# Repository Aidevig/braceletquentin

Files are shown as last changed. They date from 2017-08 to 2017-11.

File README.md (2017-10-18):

# braceletquentin
Schémas, code et documentation du bracelet développé par Quentin

#	Code
Code pour Adafruit feather bluefruit m0

# Schemas
Fichier eagles, BOM et archives avec gerber pour fabrication de la carte

# Utilitaire USB
Tentative de programme récupérant les données stockées sur le bracelet directement en USB.
Echec : trop lent.

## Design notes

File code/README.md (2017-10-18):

# LIRE CE README EN ENTIER!

# Code pour ADAFRUIT FEATHER M0 BLUEFRUIT LE

Ce code est réalisé pour une carte adafruit feather bluefruit m0 a venir souder dans le PCB assemblé de la section schema.
Ce microcontroleur utilisant un SAMD21 et non un ATMEGA, il n'est pas compatible pour les arduinos autre que ceux embarquant un SAMD21 (arduino zero, micro?, feather m0..)

# Fonctionnalités Développées

- Gestion mémoire flash : module carte SD (connection SPI)
- Connectivité bluetooth et envois alerte basique (connection SPI intégré sur le feather m0 bluefruit)
- Enregistrement de fichiers audios (WAV 8KHz) sur carte SD grâce au module microphone max4466 adafruit
- lecture de l'accélération en 3D par accéléromètre ADXL345 (connection I2C)
- lecture du rythme cardiaque par capteur cardiaque BH1790GLC (connection I2C)
- Détection alerte si le rythme cardiaque n'est pas compris entre les seuils min et max
- Pseudo Real Time Clock qui permet de dater les logs
- Lecture des seuils min et max pour le rythme cardiaque depuis un fichier texte sur la carte SD (conf.txt)
- gestion de différents types d'appuis sur un bouton poussoir (long, 1 court, 2 courts, 3 courts) BTN1 voir aidevig_pinDefinition
- Possibilité d'activer la débug console de l'IDE arduino en passant le #DEFINE DEBUG à 1

# Fonctionnement du Bracelet

- S'allume lorsqu'on branche la batterie adafruit adaptée et se recharge lorsqu'on branche le bracelet en USB.
- A l'allumage, la LED ROUGE doit clignoter quelques secondes très rapidement. Sinon, problème: réessayer plusieurs fois.
- A l'allumage, va lire les seuils limite dans le fichier conf.txt sur la carte SD
- A l'allumage, le bracelet configure sa connection bluetooth : il s'appel "GO-SAFE"
- Enregistre toutes les secondes les valeurs de l'accéléromètre x,y,z et le rythme cardiaque en datant le log dans le fichier DATALOG.txt
- Lorsqu'on appuie longtemps sur le bouton, lance un enregistrement audio qui s'arrête lorsque celui ci est relaché. La LED rouge s'allume pendant l'enregistrement
- Lorsqu'on appuie une fois sur le bouton, envois une alerte au mobile via bluetooth
- Si le rythme cardiaque est hors des seuils minCardio et maxCardio, le bracelet va proposer une alerte (LED Rouge clignotante) pendant 7 secondes.
		*Si durant ces 7 secondes, on appuie 2 fois sur le bouton, on arrête l'alerte
		*Sinon, l'alerte est envoyée.

# TO DO

- Développer l'utilisation du bluetooth en parallèle avec un développeur de l'appli mobile
- améliorer l'utilisation des LED
- Calibrer les valeurs de l'accéléromètre et du rythme cardiaque
- Calibrer les interruptions de l'accéléromètre (voir datasheet + debug console qui affiche les IT accéléromètre triggered)
ATTENTION : les IT accéléromètre sont désactivées en mode non debug
- Informer du niveau de batterie restant lors de 3 appuis (voir tuto adafruit m0 bluefruit, liens plus bas)
- Gérer le vibreur plutôt qu'une LED lors de la proposition d'alerte
- Créer des alertes automatiques sur IT accéléromètre où valeurs particulières d'accélération

# TUTO POUR PROGRAMMER LE FEATHER M0 BLUEFRUIT LE

- PREMIEREMENT : suivre ce tuto https://learn.adafruit.com/adafruit-feather-m0-bluefruit-le/setup
- télécharger l'archive Code de ce repository et extraire dans un répertoire du nom de votre choix
- Copier LE CONTENU du dossier librairies dans le dossier librairies de votre IDE Arduino ( .../mesdocuments/arduino/librairies)
- Ouvrir le fichier protoMesureQuentin.ino du répertoire protoMesureQuentin, brancher en USB le feather M0 Bluefruit LE, sélectionner le bon port dans l'IDE et cliquer sur téléverser

# En cas de problème

Contacter Quentin Van Straaten : vanstraatenquentin@gmail.com

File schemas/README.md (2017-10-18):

# Schema Electronique

Le fichier schema electronique est un fichier Eagle. Il contient le schéma électronique complet du prototype. Pour le réaliser, j'ai utilisé les schémas mis à disposition par adafruit sur ses différents modules. Ils sont aisément trouvables.

# Composants :
Microcontrolleur: 
Adafruit Feather M0 Bluefruit LE	https://www.adafruit.com/product/2995

Accéléromètre:
ADXL345 							https://www.adafruit.com/product/1231

Capteur Cardiaque:
BH1790GLC							http://www.rohm.com/web/global/products/-/product/BH1790GLC

micro:
Electret Microphone Amplifier - MAX4466 with Adjustable gain	https://www.adafruit.com/product/1063

# PCB
Le répertoire PCB contient le .brd (format eagle). Il contient également les gerbers et la BOM.

# Commander un PCB
Afin de commander un pcb assemblé il suffit d'utiliser les fichiers contenus dans l'archive PCB-BODYGUARD.rar et la BOM car les composants sont déjà correspondants entre la BOM et le .brd

Passer par le site EMSPROTO et compter deux semaines pour des prix corrects.
	
# A faire
-La carte électronique est conçue sans bouton bien que les trous soient présent pour venir en souder deux. Il faut également ajouter un vibreur sur le pin A0.
Ceci permet d'ajouter ces périphériques directement sur la structure mécanique de l'objet.
-La carte électronique vient également sans son microcontrôleur feather M0 Bluefruit qui doit être soudé dessus. Il est immaginable d'ajouter un connecteur à la place afin d'éviter d'avoir à souder le microcontrôleur.
-La batterie utilisée est une batterie adafruit compatible avec le Feather M0 Bluefruit LE, elle se recharge lorsque le bracelet est branché en USB. Le bracelet doit être allumé pour se recharger.
-Un fil de la batterie doit être coupé et soudé a un switch intégré à la structure mécanique afin de pouvoir allumer et éteindre le bracelet 	
	
# ATTENTION
Afin d'optimiser l'espace sur la carte, j'ai supprimé les boutons poussoirs. Il ne reste que le trou pour les connecter aux pins du microcontrôleur. Il faudra également connecter l'autre entrée à la masse.
Par conséquent, les fichiers eagles du schéma et de la board ne sont plus linkés. AUCUNE MODIFICATION SUR L'UN N'AURA D'EFFET SUR L'AUTRE

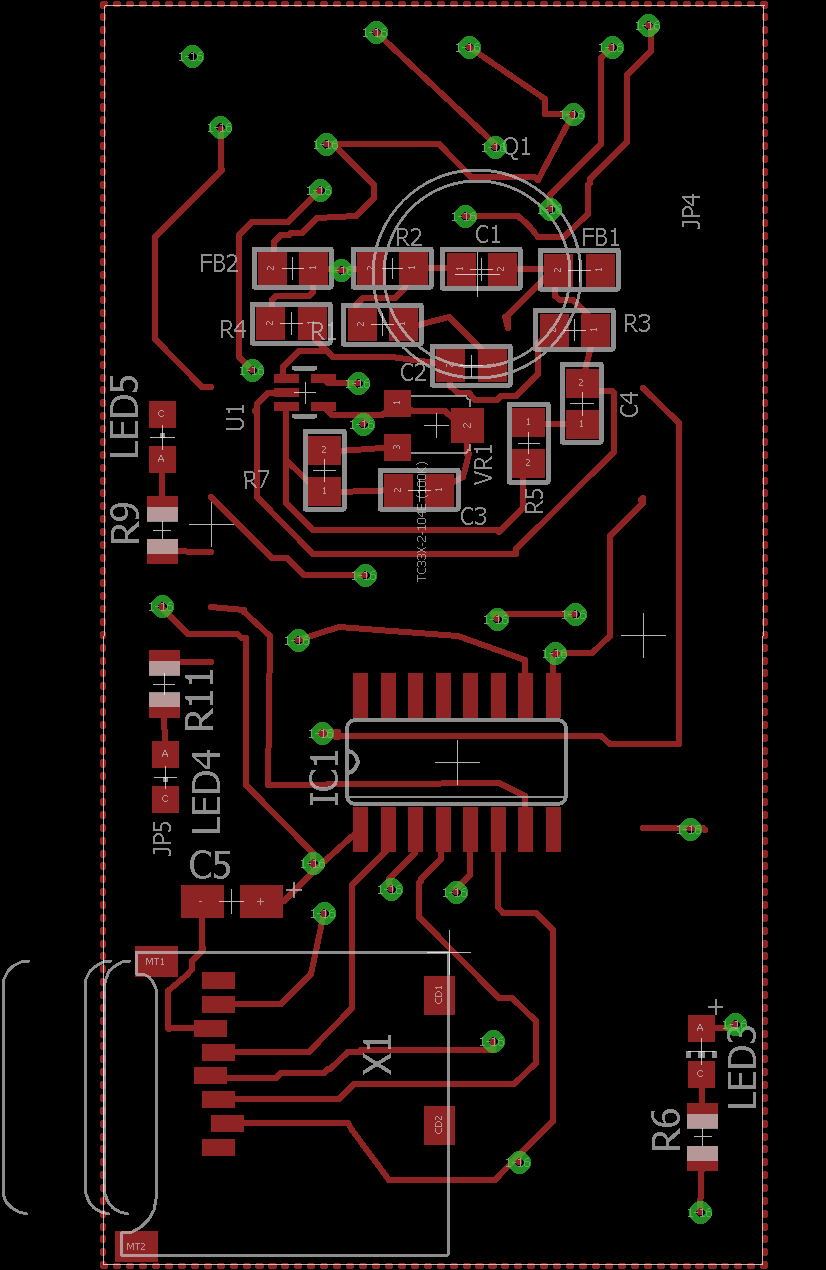
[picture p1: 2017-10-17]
schemas/PCB/gerbers/TOP.png

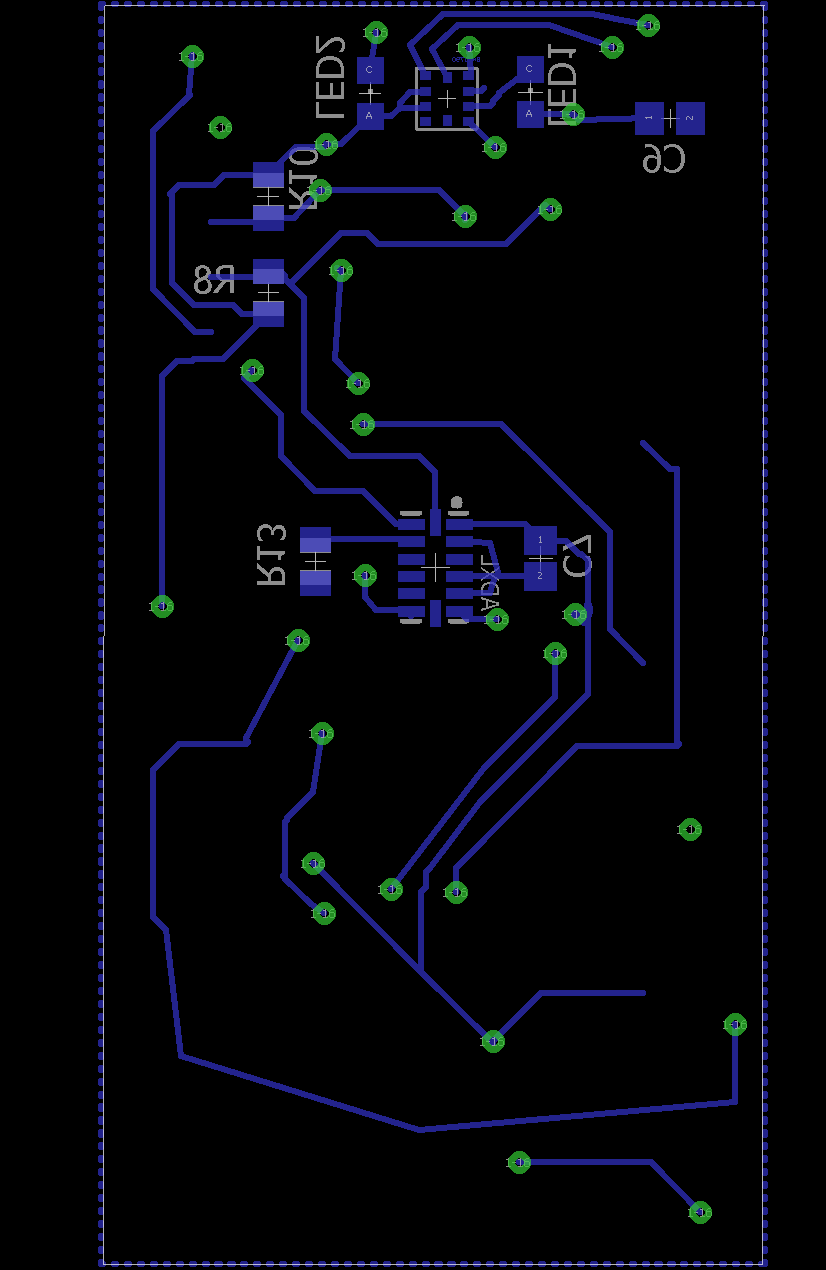
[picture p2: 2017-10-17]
schemas/PCB/gerbers/BOT.png

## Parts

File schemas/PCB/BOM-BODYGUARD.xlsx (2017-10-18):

Désignation | Quantity | Manufacturer | Reference Manufacturer | Supplier | Reference Supplier | MOUNTING TECHNOLOGY | Designator
Optical Sensor For Heart Rate Monitor | 1 | ROHM SEMICONDUCTOR | BH1790GLC-E2 | DIGIKEY | BH1790GLC-E2CT-ND | SMD | BH1790
LED BLUE-GREEN CLEAR 0603 SMD | 2 | ROHM SEMICONDUCTOR | SMLE13EC8TT86 | DIGIKEY | 846-1178-1-ND | SMD | LED1, LED2
LED green 0805 CMS | 1 | DIALIGHT | 5988270107F | FARNELL | 1850749 | SMD | LED5
LED RED 0805 CMS | 2 | DIALIGHT | 5988210107F | FARNELL | 1850747 | SMD | LED3, LED4
ADXL345BCCZ ACCELEROMETRE 3 AXES | 1 | ANALOG DEVICES | ADXL345BCCZ | FARNELL | 1853935 | SMD | ADXL
Buffer, Non-Inverseur | 1 | TEXAS INSTRUMENTS | CD74HC4050M | FARNELL | 1643824 | SMD | IC1
Connecteur carte SD | 1 | Adafruit | 1660 | MOUSER | 485-1660 | SMD | X1
Condensateur céramique multicouche CMS 100pF | 1 | MULTICOMP | MC0805N101J500CT | FARNELL | 1759203 | SMD | C3
Condensateur céramique multicouche CMS 0,01uF | 1 | MULTICOMP | MC0805F103Z500CT | FARNELL | 2665973 | SMD | C2
Condensateur céramique multicouche CMS 0,1uF | 2 | AVX | 08055C104KAT2A | FARNELL | 499687 | SMD | C1, C7
Condensateur céramique multicouche CMS 1uF | 1 | WALSIN | 0805B105K160CT | FARNELL | 2496946 | SMD | C6
Condensateur céramique multicouche CMS 10uF | 2 | WALSIN | 0805F106Z100CT | FARNELL | 2496998 | SMD | C4, C5
Resistance CMS 1K | 6 | MULTICOMP | MCHP05W4F1001T5E | FARNELL | 1576459 | SMD | R1, R2, R5, R6, R9, R11
Resistance CMS 10K | 3 | MULTICOMP | MCHP05W4F1002T5E | FARNELL | 1576473 | SMD | R8, R10, R13
Resistance CMS 22K | 1 | Welwyn | WCR0805-22KFI | FARNELL | 1099809 | SMD | R7
Resistance CMS 1M | 2 | MULTICOMP | MCHP05W4F1004T5E | FARNELL | 1576507 | SMD | R3, R4
Ferrite Beads 100MHz 600Ohm | 2 | WURTH ELEKTRONIK | 742792040 | MOUSER | 710-742792040 | SMD | FB1, FB2
Microphone | 1 | CUI INC | CMA-4544PF-W | DIGIKEY | 490-CMA-4544PF-W | Trans | Q1
Potentimètre variable 100KOhms | 1 | BOURNS | TC33X-2-104E | FARNELL | 1689864 | SMD | VR1
Ampli audio | 1 | MAXIMUM INTEGRATED PRODUCTS | MAX4466EXK+T | FARNELL | 2514501 | SMD | U1

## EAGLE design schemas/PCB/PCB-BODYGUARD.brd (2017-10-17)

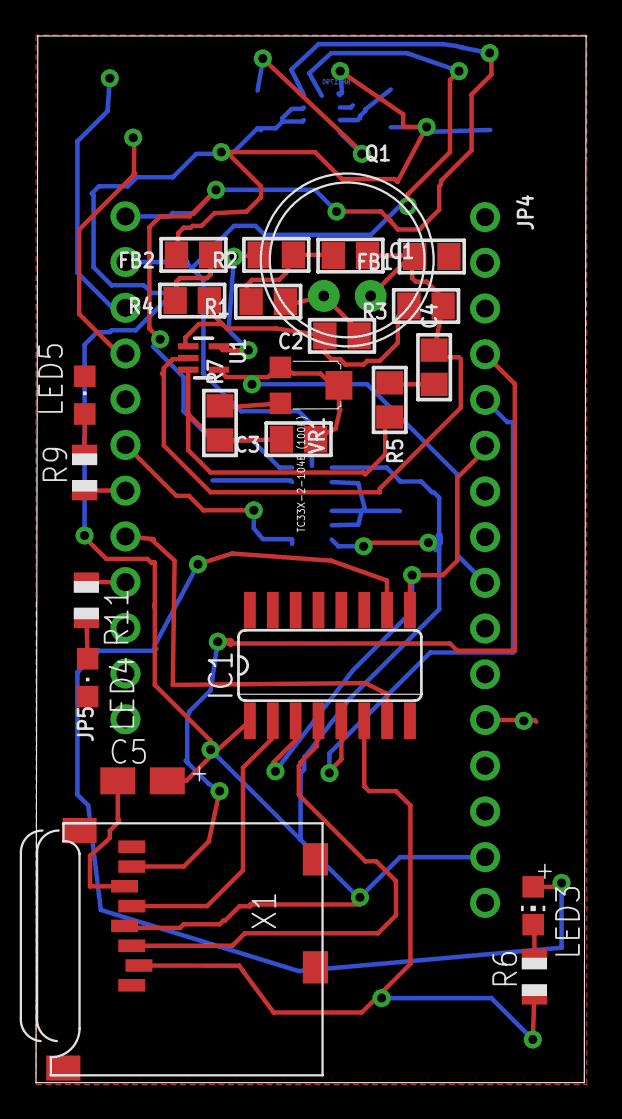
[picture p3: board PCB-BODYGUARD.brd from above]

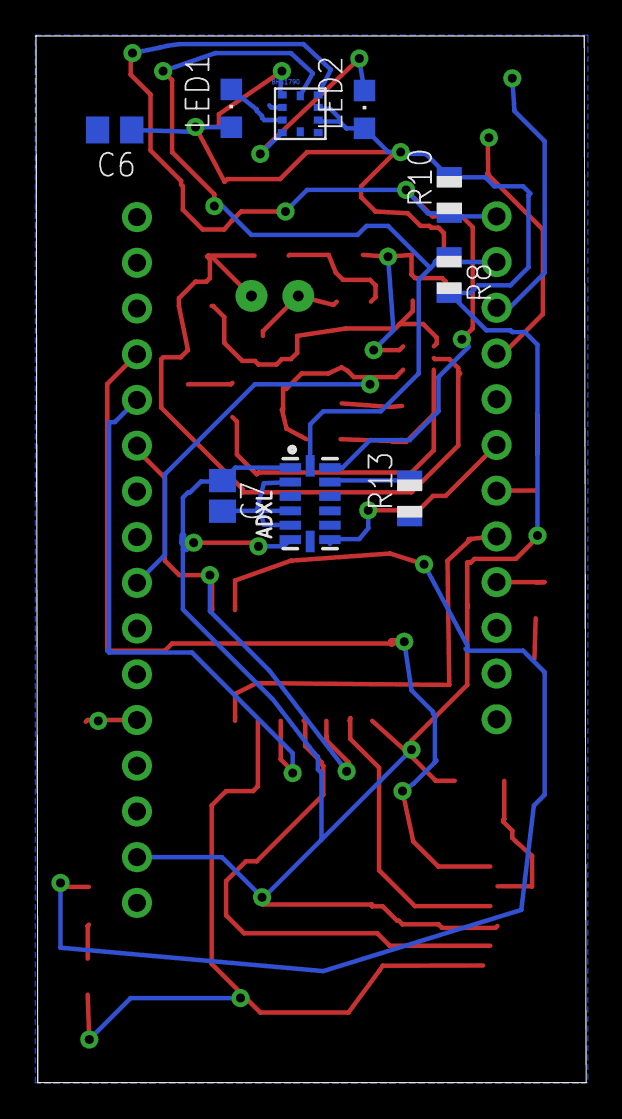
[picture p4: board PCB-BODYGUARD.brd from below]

Board: 2 copper layers, 30.6 x 58.1 mm, 35 parts (9 on the bottom side), 30 nets.

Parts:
ADXL: LGA14
BH1790: BH1790
C1: 0.1µF; 0805
C2: 0.01uF; 0805
C3: 100pF; 0805
C4: 10uF; 0805
C5: 10uF; A/3216-18R
C6: 1uF; C0805
C7: 0.1uF; C0805
FB1, FB2: FERRITE; 0805
IC1: 4050D; SO16
JP4: 1X16_ROUND
JP5: 1X12_ROUND
LED1, LED2, LED5: green; CHIPLED_0805
LED3: RED; CHIP-LED0805
LED4: Red; CHIPLED_0805
Q1: CMA-4544PF-W; ELECTRET_9.7
R1, R2, R5: 1K; 0805
R3, R4: 1M; 0805
R6, R9, R11: 1K; R0805
R7: 22K; 0805
R8, R10, R13: 10K; R0805
U1: MAX4466EXK+T; SC70-5
VR1: TC33X-2-104E (100K); TRIMPOT_BOURNS_TC33X-2
X1: MICROSD

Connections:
+3V3: ADXL.1, ADXL.6, BH1790.TEST2, BH1790.VCC, BH1790.VCC2, C5.+, C6.1, C7.1, FB2.2, IC1.1, JP4.15, LED1.A, LED2.A, R8.2, R10.2, X1.4
A3: C3.1, JP4.9, U1.4, VR1.1, VR1.2
AGND: C1.2, C4.2, FB1.2, Q1.-, R3.1, U1.2
AVCC: FB2.1, R2.2, R4.2, U1.5
D10: ADXL.8, JP5.7
D11: JP5.6, R9.1
D12: IC1.7, JP5.5
D13: JP5.4, R11.1
GND: ADXL.2, ADXL.4, ADXL.5, BH1790.GND, BH1790.TEST1, C5.-, C6.2, C7.2, FB1.1, IC1.8, IC1.11, IC1.14, JP4.13, LED4.C, LED5.C, R13.1, X1.6, X1.MT1, X1.MT2
MISO: JP4.4, X1.7
MOSI: IC1.5, JP4.5
unnamed: C3.2, R5.2, R7.1, U1.3
unnamed: R7.2, VR1.3
unnamed: C2.1, Q1.+, R1.1
unnamed: C1.1, R1.2, R2.1
unnamed: C2.2, R3.2, R4.1, U1.1
unnamed: BH1790.LED1, LED1.C
unnamed: C4.1, R5.1
unnamed: IC1.10, LED3.A
unnamed: IC1.2, X1.5
unnamed: IC1.6, R6.1, X1.2
unnamed: LED3.C, R6.2
unnamed: IC1.4, X1.3
unnamed: BH1790.LED2, LED2.C
unnamed: LED5.A, R9.2
unnamed: LED4.A, R11.2
SCK: IC1.3, IC1.9, JP4.6
SCL: ADXL.14, BH1790.SCL, JP5.11, R8.1
SDA: ADXL.13, BH1790.SDA, JP5.12, R10.1
SDO/ADDR: ADXL.12, R13.2

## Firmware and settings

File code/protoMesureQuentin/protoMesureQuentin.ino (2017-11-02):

/**************************************************************************/
/*!
    @section LICENSE

    Software License Agreement (BSD License)

    Copyright (c) 2017, Aidevig
    All rights reserved.

    Redistribution and use in source and binary forms, with or without
    modification, are permitted provided that the following conditions are met:
    1. Redistributions of source code must retain the above copyright
    notice, this list of conditions and the following disclaimer.
    2. Redistributions in binary form must reproduce the above copyright
    notice, this list of conditions and the following disclaimer in the
    documentation and/or other materials provided with the distribution.
    3. Neither the name of the copyright holders nor the
    names of its contributors may be used to endorse or promote products
    derived from this software without specific prior written permission.

    THIS SOFTWARE IS PROVIDED BY THE COPYRIGHT HOLDERS ''AS IS'' AND ANY
    EXPRESS OR IMPLIED WARRANTIES, INCLUDING, BUT NOT LIMITED TO, THE IMPLIED
    WARRANTIES OF MERCHANTABILITY AND FITNESS FOR A PARTICULAR PURPOSE ARE
    DISCLAIMED. IN NO EVENT SHALL THE COPYRIGHT HOLDER BE LIABLE FOR ANY
    DIRECT, INDIRECT, INCIDENTAL, SPECIAL, EXEMPLARY, OR CONSEQUENTIAL DAMAGES
    (INCLUDING, BUT NOT LIMITED TO, PROCUREMENT OF SUBSTITUTE GOODS OR SERVICES;
    LOSS OF USE, DATA, OR PROFITS; OR BUSINESS INTERRUPTION) HOWEVER CAUSED AND
    ON ANY THEORY OF LIABILITY, WHETHER IN CONTRACT, STRICT LIABILITY, OR TORT
    (INCLUDING NEGLIGENCE OR OTHERWISE) ARISING IN ANY WAY OUT OF THE USE OF THIS
    SOFTWARE, EVEN IF ADVISED OF THE POSSIBILITY OF SUCH DAMAGE.
*/
/**************************************************************************/


/*****************************************************************************
  HeartRate.ino

 Copyright (c) 2016 ROHM Co.,Ltd.

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
 THE SOFTWARE IS PROVIDED "AS IS", WITHOUT WARRANTY OF ANY KIND, EXPRESS OR
 IMPLIED, INCLUDING BUT NOT LIMITED TO THE WARRANTIES OF MERCHANTABILITY,
 FITNESS FOR A PARTICULAR PURPOSE AND NONINFRINGEMENT. IN NO EVENT SHALL THE
 AUTHORS OR COPYRIGHT HOLDERS BE LIABLE FOR ANY CLAIM, DAMAGES OR OTHER
 LIABILITY, WHETHER IN AN ACTION OF CONTRACT, TORT OR OTHERWISE, ARISING FROM,
 OUT OF OR IN CONNECTION WITH THE SOFTWARE OR THE USE OR OTHER DEALINGS IN
 THE SOFTWARE.
******************************************************************************/

///////////////////////////////DO NOT TOUCH ANY OF THESE LIBRAIRIES/////////////////////////
///***Librairies Natives Android
#include <SPI.h>
#include <SD.h>
#include <Wire.h>
#if not defined (_VARIANT_ARDUINO_DUE_X_) && not defined (_VARIANT_ARDUINO_ZERO_)
  #include <SoftwareSerial.h>
#endif
///***Librairies Natives Adafruit pour le fonctionnement du bluetooth
#include "Adafruit_BLE.h"
#include "Adafruit_BluefruitLE_SPI.h"
///***Librairies Délivrées par Rohm pour le fonctionnement du capteur cardiaque
#include <BH1790GLC.h>
extern "C" {
#include <hr_bh1790.h>
}
///*******Librairie Open Source pour l'utilisation de l'ADXL345
#include <ADXL345.h>


////////////////////////////CHANGES CAN BE MADE ON THESE LIBRAIRIES/////////////////////////////
///*****Librairies développées pour le proto mesure Aidevig
///*****Elles contiennent les fonctions qui gèrent les différents périphériques

////////////Mapping HARDWARE/////////
#include <aidevig_pinDefinition.h>   // CONTIENT #DEFINE DEBUG QUI ACTIVE LA DEBUG CONSOLE


#include <aidevig_timers.h> //**Gère l'initialisation, la mise en route et l'arrêt des timers
                    //**Initialise le timer TC4 pour IT sur overflow à 8Khz
                    //**Initialise le timer TC5 pour IT sur overflow à 32Hz

#include <aidevig_ADC.h>  //**Gère l'initialisation et la mise en route du convertisseur analog numérique
                 //** Contient aussi la fonction de lecture rapide afin de pouvoir respecter les 8Khz d'échantillonage pour enregistrement audio 

#include <aidevig_RTC.h> //**Gère une horloge temps réelle qui permet de dater les logs si elle est mise à l'heure grâce au téléphone

#include <aidevig_WAVrecorder.h> //**Gère l'enregistrement de fichiers WAV et l'envois des fichiers en USB

#include <aidevig_utilitaire.h> //**Gère l'algorithmie basique s'appuyant sur les fonctions arduino
                        //**  +la gestion du bluetooth
                        //**  +la gestion de l'accéléromètre
                        //**  +la gestion du capteur cardiaque
                        //**  +la gestion des boutons et des gpios



Adafruit_BluefruitLE_SPI ble(BLUEFRUIT_SPI_CS, BLUEFRUIT_SPI_IRQ, BLUEFRUIT_SPI_RST);


void setup() {
  
  Serial.begin(9600);
  if(DEBUG) wait5sec();
  startBluetooth();
  /// A changer lorsque l'appli pourra envoyer l'heure et la date lors de l'appairage
  setTimestamp(2017,0,0,0,0);
  adxlInit();
  setTimer();
  initHeader();
  pinConfig();
  sdStart();
  cardioInit();
  getSeuils();
  adc_init();
  blinkFast(LED_RED);
}

void loop() {
  ///GESTION DE L'APPUI SUR LE BOUTON
  int btn1 = managebtn(BTN_1);
  //SI APPUI LONG, ON LANCE L'ENREGISTREMENT AUDIO
  if(btn1 ==START_RECORD){
    if(DEBUG) Serial.println("Enregistrement...");
    startRec(); 
  }
  ///ARRET DE L'ENREGISTREMENT LORSQUE BOUTON RELACHE
  if(btn1 ==STOP_RECORD){
    stopRec();
    if(DEBUG) Serial.println("Fin d'enregistrement");
  }
  ///ENVOIS d'UNE ALERTE SI UNE PRESSION SUR LE BOUTON
  if(btn1 == SEND_ALERT) sendAlert();
  if(btn1 == STOP_ALERT) stopAlert();
  
  if(!record){
   ///*******GESTION COMMUNICATION USB
    if(Serial.available()>0){
        if(waitCommand()=='G'){
          sendLast();
        }
        if(waitCommand()=='A'){
          sendAudio();
          sendLog();
        }
      }
    alertAutoCardio();  
      
  ///*************Gestion de l'accéléromètre    
  adxl.readAccel(&x, &y, &z); //read the accelerometer values and store them in variables  x,y,z
  //read interrupts source and look for triggerd actions
  /*if(DEBUG){
    if(digitalRead(ACCELEROMETRE_IT)){ 
        adxlInterrupts();
    }
  }*/
  ///**********GESTION Capteur cardiaque
  resetDataCardio();
  ///FLAG 32HZ
  if (timer_flg) {
    ret16 = hr_bh1790_Calc(s_cnt_freq);
    if (ret16 == ERROR_NONE) {
      s_cnt_freq++;
      ///tourne chaque seconde
      if (s_cnt_freq >= SAMPLING_CNT_32HZ) {
        s_cnt_freq = 0;
        hr_bh1790_GetData(&bpm, &wearing);
        if(DEBUG) displayLog();
        ///ENREGISTRE LES DONNEES SUR LA CARTE SD
        refreshTimestamp();
        saveLog();
        }
      } else {
        if(DEBUG){ Serial.println(F("Error: hr_bh1790_Calc function"));Serial.print(F("ret16 = "));Serial.println(ret16, HEX);}
      }
      timer_flg = false;
    }
  }
  ///Ecris les buffer audio lorsqu'ils sont plein
  writeWav();
}

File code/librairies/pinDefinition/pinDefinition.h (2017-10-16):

#ifndef PINDEFINITION_H_INCLUDED
#define PINDEFINITION_H_INCLUDED

#define BLUEFRUIT_SPI_CS 8
#define BLUEFRUIT_SPI_IRQ 7
#define BLUEFRUIT_SPI_RST 4

#define ADCPIN A3
#define SD_PIN  12
#define ACCELEROMETRE_IT 10
#define BTN_1 6
#define BTN_2 5
#define LED_RED 13
#define LED_GREEN 11

#define VIBREUR A0

#endif // PINDEFINITION_H_INCLUDED

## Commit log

2017-08-31 Test
    Premier test d'ajout de fichier
2017-08-31 file test
    essais d'upload de file pour voir l'effet sur mon répertoire local
2017-08-31 Fin des test
    Après test du revert, push pull, Suppression des fichiers inutiles pour
    la suite. Prêt à démarrer.
2017-08-31 Schemas du proto mesure
    Mise en vrac des différents fichiers.
    [protomesure.brd, protomesure.sch, protomesure2.brd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]
2017-10-02 design final du pcb
    [protomesurefinal.brd]
2017-10-16 En vue de la Review
    Code mis au propre
    + ajout des différents codes boutons et débounce
    + ajout d'une pseudo Rtc
2017-10-17 ajout des fichiers PCB
    [BOM-BODYGUARD.xlsx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]
2017-10-17 Ajout des licenses et explication des librairies
2017-10-17 Déplacement de l'archive pcb-bdyguar.rar
2017-10-17 Ajout de la license
2017-10-17 ajout de la license aidevig
2017-10-17 Correctif envois des données
    [aidevig_WAVrecorder.cpp, protoMesureQuentin.ino]
2017-10-18 Utilitaire USB + alerte autocardio + seuils from SD
    [BOM-BODYGUARD.xlsx]
2017-11-02 suppression gestion des interruptions car bug avec Accéléromètre
    [protoMesureQuentin.ino]

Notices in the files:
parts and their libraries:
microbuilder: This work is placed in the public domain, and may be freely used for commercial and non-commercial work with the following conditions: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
